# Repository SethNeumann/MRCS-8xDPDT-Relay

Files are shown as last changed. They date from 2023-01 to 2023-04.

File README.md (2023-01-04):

# REPO NAME: MRCS-8xDPDT-Relay
## License: Creative Commons Attribution-NonCommercial-ShareAlike

MRCS-8xDPDT-Relay - 8 channel DPDT Relay board with Arduino Relay compatible input

8 G5/JRC-19F/DY2 style relays, canbe powered from 5V from Arduino Relay Controller or any DC voltage coil available up to 48.
Uses ULN-2803 as buffer and for snubber diodes.
One side of each relay has cuttable traces normally set to +relayV and GND

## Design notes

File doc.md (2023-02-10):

MRCS-8xDPDT-Relay - 8 channel DPDT Relay board with Arduino Relay compatible input

8 G5V2/JRC-19F/DY2 style relays, can be powered from 5V from Arduino Relay Controller or any DC voltage coil available up to 48VDC.
Uses ULN-2803 as driver and for snubber diodes.

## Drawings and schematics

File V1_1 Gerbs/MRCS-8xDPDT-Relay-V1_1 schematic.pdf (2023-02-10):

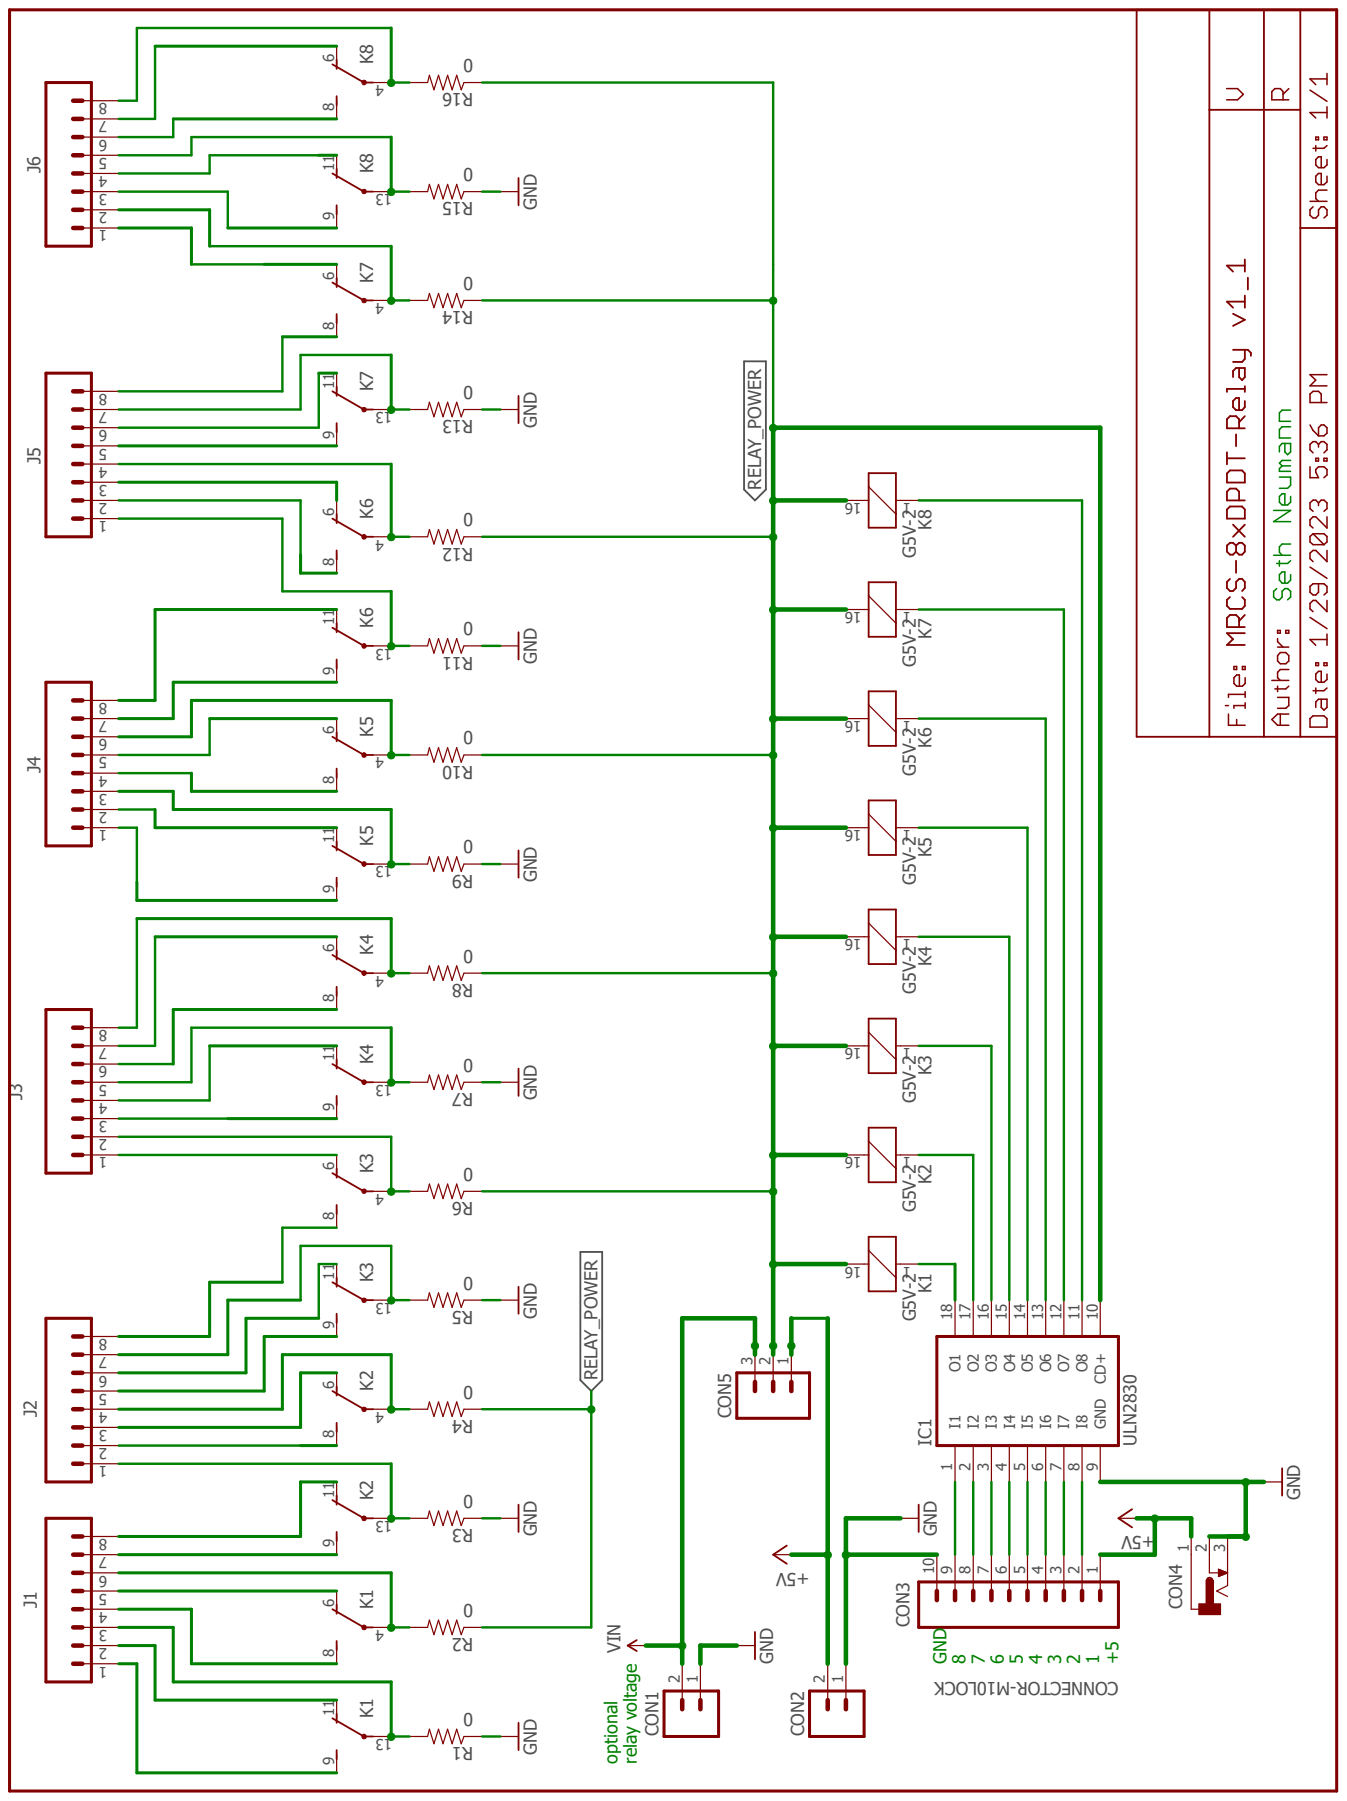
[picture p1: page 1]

+5V GND VIN G5V-2 G5V-2 G5V-2 G5V-2 G5V-2 G5V-2 G5V-2 G5V-2 0000000000000000 GND GND GND GND GND GND GND GND 10987654321 CON3 IC1I1 1 I2 2 I3 3 I4 4 I5 5 I6 6 I7 7 I8 8 O8 11 O1 18 O2 17 O3 16 O4 15 O5 14 O6 13 O7 12 CD+ 10 GND 9 12345678 J1 12345678 J2 12345678 J3 12345678 J4 12345678 J5 12345678 J6 CON4 123 CON1 21 CON2 21 321 CON5 K1

R16 RELAY_POWER RELAY_POWER GND 87654321+5 optional relay voltage

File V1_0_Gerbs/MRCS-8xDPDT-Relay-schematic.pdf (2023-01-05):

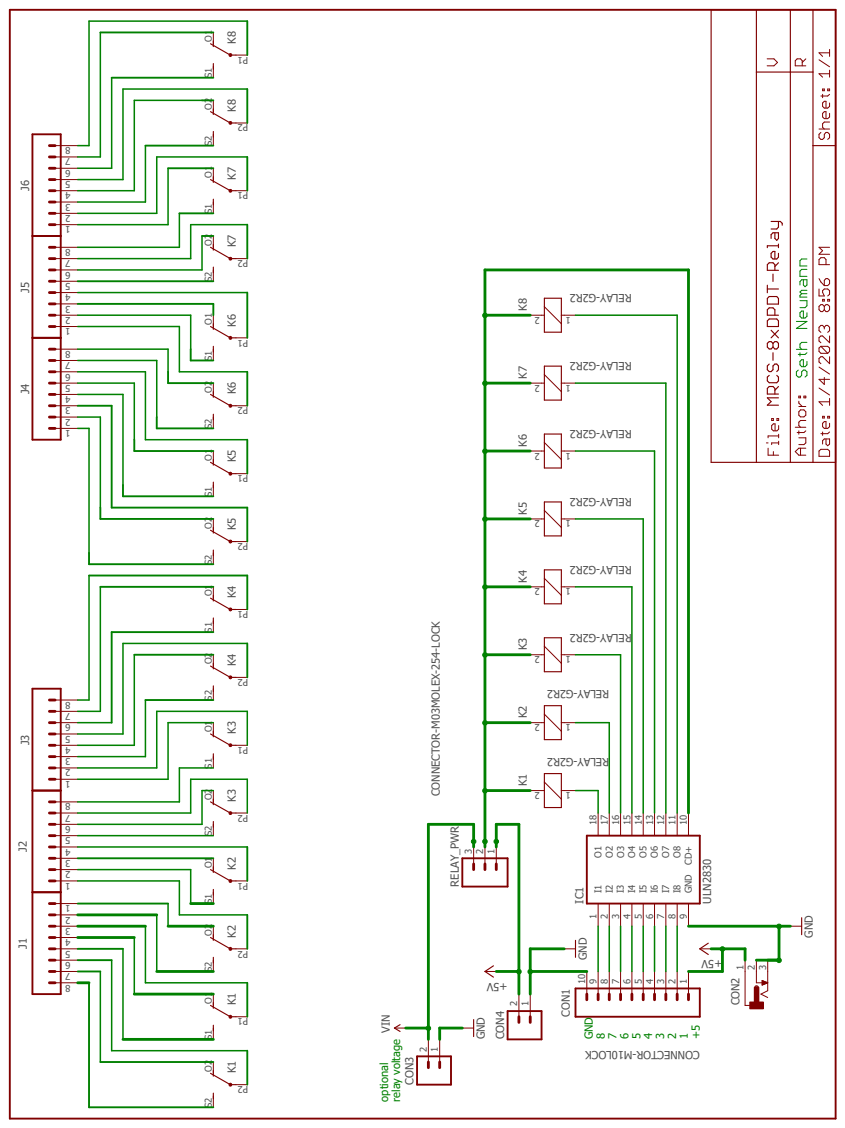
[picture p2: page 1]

P2 IC1I1 1 I2 2 I3 3 I4 4 I5 5 I6 6 I7 7 I8 8 O8 11 O1 18 O2 17 O3 16 O4 15 O5 14 O6 13 O7 12 CD+ 10 GND 9 12345678 J1 12345678 J2 12345678 J3 12345678 J4 12345678 J5 12345678 J6 CON2 123 CON3 21 CON4 21 321 RELAY_PWR GND 87654321+5 optional relay voltage

+5V GND VIN CONNECTOR-M03MOLEX-254-LOCK 10987654321 CON1 2 1 K1 O1 K1 S1 P1 O2 K1 S2

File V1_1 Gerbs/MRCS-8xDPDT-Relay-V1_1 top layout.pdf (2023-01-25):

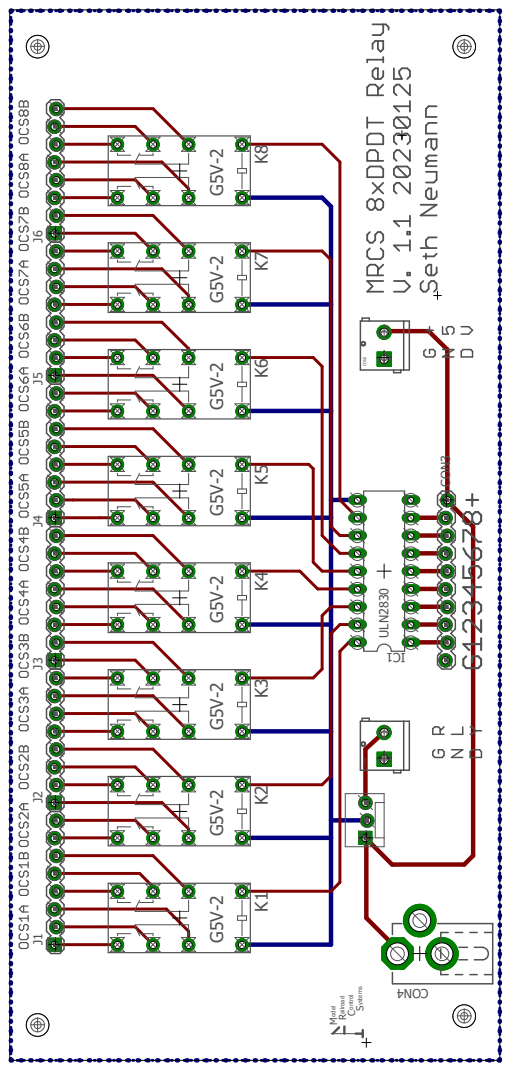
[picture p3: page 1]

MRCSystems ontrol ailroad odel CON3

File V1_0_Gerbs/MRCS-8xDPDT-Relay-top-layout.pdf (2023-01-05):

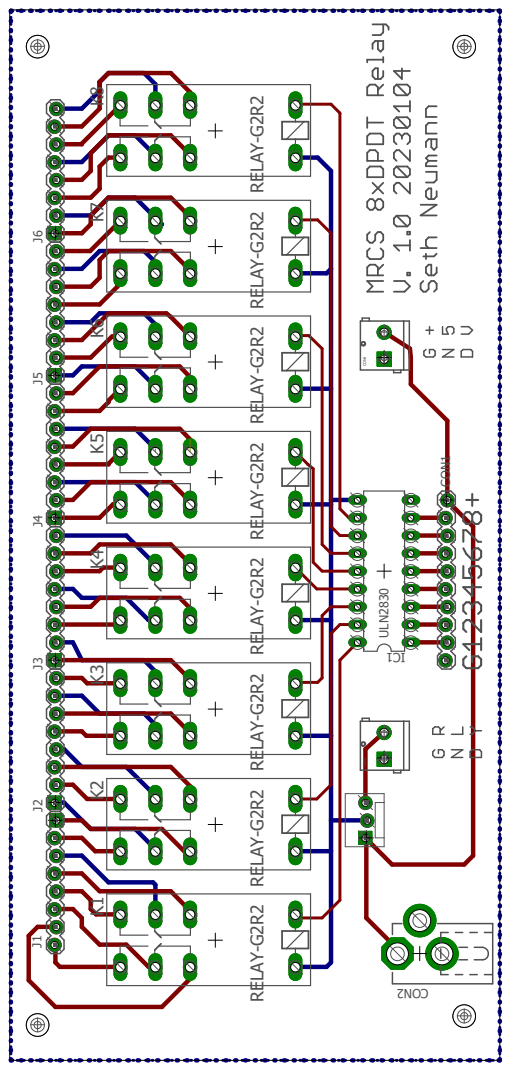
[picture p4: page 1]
CON1 K1 K2 K3 K4 K5 K6 K7 K8 IC1 J1 J2 J3 J4 J5 J6

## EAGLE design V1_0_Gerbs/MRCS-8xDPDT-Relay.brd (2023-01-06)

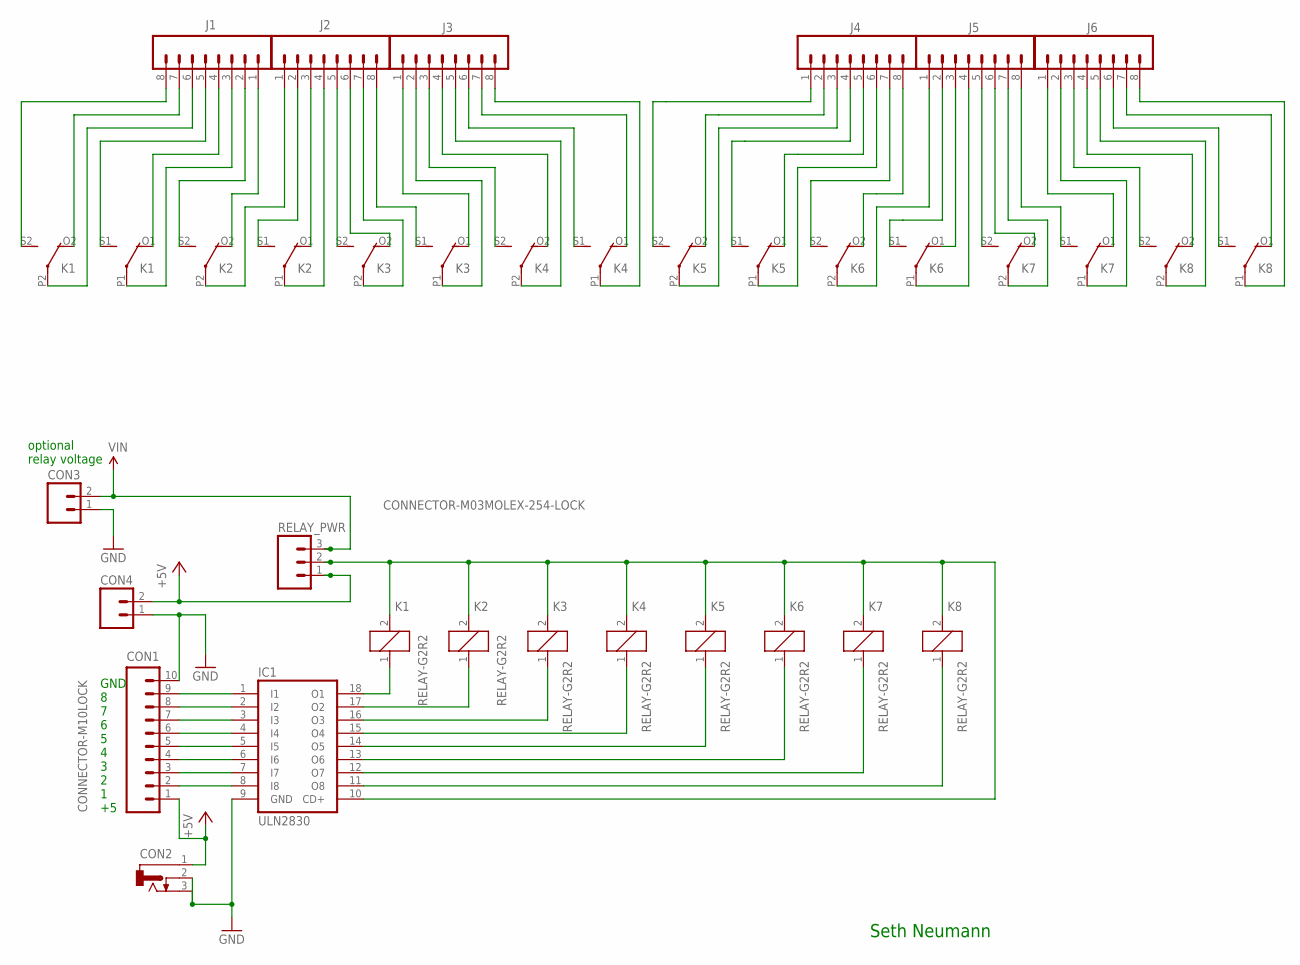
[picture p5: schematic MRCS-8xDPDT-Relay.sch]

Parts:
CON1: CONNECTOR-M10LOCK; 1X10_LOCK
CON2: CONNECTOR-DC-POWER-RA; DCJ0202
CON3, CON4: CONNECTOR-M023.5MM-LOCK; SCREWTERMINAL-3.5MM-2_LOCK
IC1: ULN2830; DIL18
J1, J2, J3, J4, J5, J6: CONNECTOR-M08LOCK; 1X08_LOCK
K1, K2, K3, K4, K5, K6, K7, K8: RELAY-G2R2; G2R2
RELAY_PWR: CONNECTOR-M03MOLEX-254-LOCK; MOLEX-1X3_LOCK

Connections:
+5V: CON1.1, CON2.1, CON4.2 (B), RELAY_PWR.1
GND: CON1.10, CON2.2, CON2.3, CON3.1 (A), CON4.1 (A), IC1.9 (GND)
unnamed: CON1.9, IC1.1 (I1)
unnamed: CON1.8, IC1.2 (I2)
unnamed: CON1.7, IC1.3 (I3)
unnamed: CON1.6, IC1.4 (I4)
unnamed: CON1.5, IC1.5 (I5)
unnamed: CON1.4, IC1.6 (I6)
unnamed: CON1.3, IC1.7 (I7)
unnamed: CON1.2, IC1.8 (I8)
unnamed: IC1.17 (O2), K2.1
unnamed: IC1.16 (O3), K3.1
unnamed: IC1.15 (O4), K4.1
unnamed: IC1.14 (O5), K5.1
unnamed: IC1.18 (O1), K1.1
unnamed: IC1.13 (O6), K6.1
unnamed: IC1.12 (O7), K7.1
unnamed: IC1.11 (O8), K8.1
unnamed: IC1.10 (CD+), K1.2, K2.2, K3.2, K4.2, K5.2, K6.2, K7.2, K8.2, RELAY_PWR.2
unnamed: J1.8, K1.S2 (S)
unnamed: J1.7, K1.O2 (O)
unnamed: J1.6, K1.P2
unnamed: J1.5, K1.S1 (S)
unnamed: J2.3, K2.O1 (O)
unnamed: J1.3, K1.P1
unnamed: J1.2, K2.S2 (S)
unnamed: J1.1, K2.O2 (O)
unnamed: J2.1, K2.P2
unnamed: J2.2, K2.S1 (S)
unnamed: J4.3, K5.P2
unnamed: J2.4, K2.P1
unnamed: J2.7, K3.P2
unnamed: J2.6, K3.O2 (O)
unnamed: J2.8, K3.S1 (S)
unnamed: J2.5, K3.S2 (S)
unnamed: J3.1, K3.O1 (O)
unnamed: J3.2, K3.P1
unnamed: J3.3, K4.S2 (S)
unnamed: J3.4, K4.O2 (O)
unnamed: J3.5, K4.P2
unnamed: J3.6, K4.S1 (S)
unnamed: J3.7, K4.O1 (O)
unnamed: J3.8, K4.P1
unnamed: J5.4, K6.P1
unnamed: J5.5, K7.S2 (S)
unnamed: J5.6, K7.O2 (O)
unnamed: J5.7, K7.P2
unnamed: J5.8, K7.S1 (S)
unnamed: J6.1, K7.O1 (O)
unnamed: J6.2, K7.P1
unnamed: J6.3, K8.S2 (S)
unnamed: J6.4, K8.O2 (O)
unnamed: J6.5, K8.P2
unnamed: J6.6, K8.S1 (S)
unnamed: J6.7, K8.O1 (O)
unnamed: J6.8, K8.P1
unnamed: J5.3, K6.O1 (O)
unnamed: J5.2, K6.S1 (S)
unnamed: J5.1, K6.P2
unnamed: J4.8, K6.O2 (O)
unnamed: J4.7, K6.S2 (S)
unnamed: J4.6, K5.P1
unnamed: J4.5, K5.O1 (O)
unnamed: J4.4, K5.S1 (S)
unnamed: J4.2, K5.O2 (O)
unnamed: J4.1, K5.S2 (S)
unnamed: J1.4, K1.O1 (O)
VIN: CON3.2 (B), RELAY_PWR.3

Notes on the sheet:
Seth Neumann
GND 8 7 6 5 4 3 2 1 +5
optional relay voltage

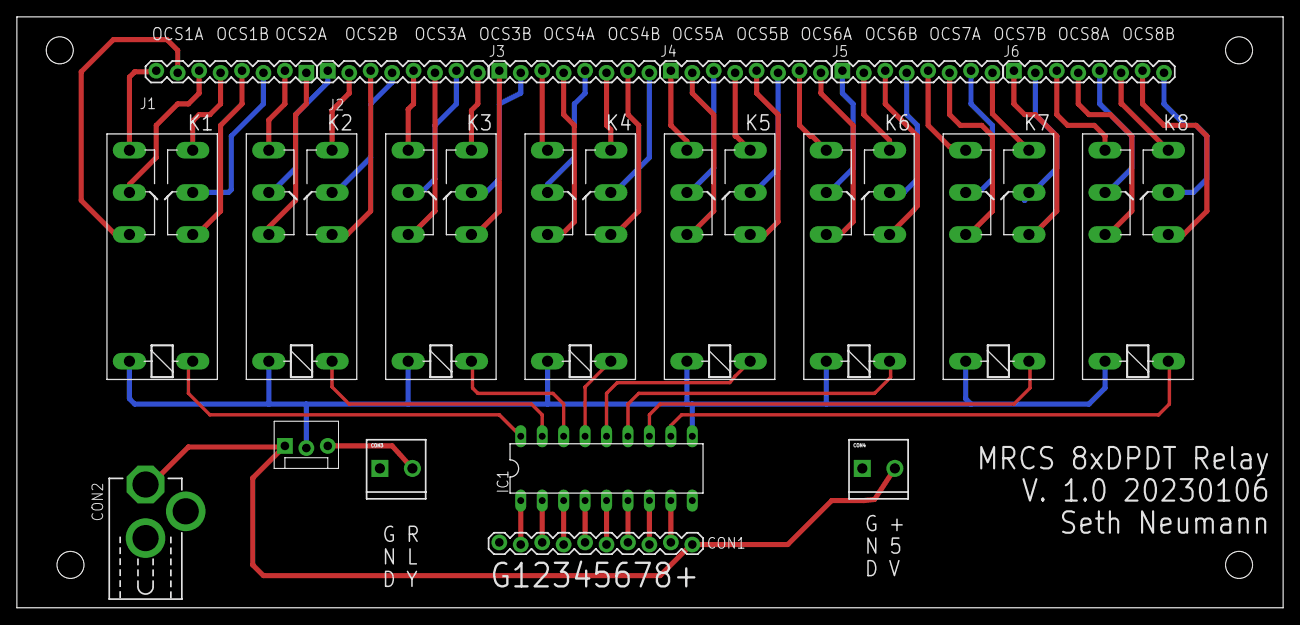
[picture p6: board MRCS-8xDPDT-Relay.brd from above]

Board: 2 copper layers, 150.0 x 70.0 mm, 23 parts (0 on the bottom side), 68 nets.

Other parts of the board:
U$1: CA-PROP65WARNING
U$2: MRCSLOGOBTM
U$3: MRCSLOGOTOP

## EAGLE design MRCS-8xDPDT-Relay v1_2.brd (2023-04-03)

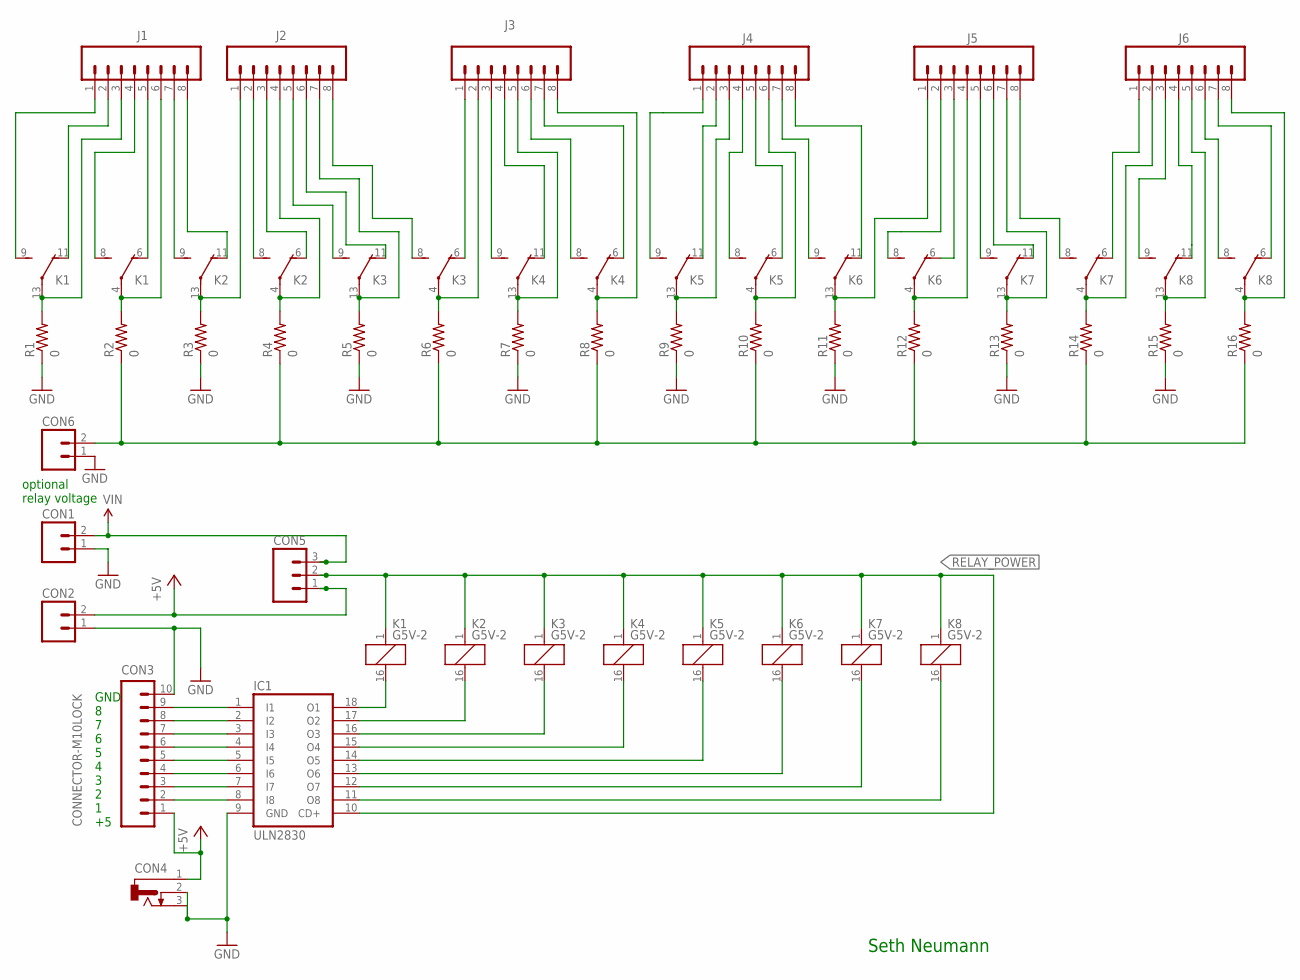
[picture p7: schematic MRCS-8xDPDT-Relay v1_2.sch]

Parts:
CON1, CON2, CON6: CONNECTOR-M023.5MM-LOCK; SCREWTERMINAL-3.5MM-2_LOCK
CON3: CONNECTOR-M10LOCK; 1X10_LOCK
CON4: CONNECTOR-DC-POWER-RA; DCJ0202
CON5: CONNECTOR-M03MOLEX-254-LOCK; MOLEX-1X3_LOCK
IC1: ULN2830; DIL18
J1, J2, J3, J4, J5, J6: CONNECTOR-M08LOCK; 1X08_LOCK
K1, K2, K3, K4, K5, K6, K7, K8: G5V-2
R1, R2, R3, R4, R5, R6, R7, R8, R9, R10, R11, R12, R13, R14, R15, R16: 0; CUT-R

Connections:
+5V: CON2.2 (B), CON3.1, CON4.1, CON5.1
AUX_COMMON: CON6.2 (B), R2.P2 (1), R4.P2 (1), R6.P2 (1), R8.P2 (1), R10.P2 (1), R12.P2 (1), R14.P2 (1), R16.P2 (1)
GND: CON1.1 (A), CON2.1 (A), CON3.10, CON4.2, CON4.3, CON6.1 (A), IC1.9 (GND), R1.P2 (1), R3.P2 (1), R5.P2 (1), R7.P2 (1), R9.P2 (1), R11.P2 (1), R13.P2 (1), R15.P2 (1)
unnamed: CON3.9, IC1.1 (I1)
unnamed: CON3.8, IC1.2 (I2)
unnamed: CON3.7, IC1.3 (I3)
unnamed: CON3.6, IC1.4 (I4)
unnamed: CON3.5, IC1.5 (I5)
unnamed: CON3.4, IC1.6 (I6)
unnamed: CON3.3, IC1.7 (I7)
unnamed: CON3.2, IC1.8 (I8)
unnamed: IC1.17 (O2), K2.16 (2)
unnamed: IC1.16 (O3), K3.16 (2)
unnamed: IC1.15 (O4), K4.16 (2)
unnamed: IC1.14 (O5), K5.16 (2)
unnamed: J1.7, K2.9 (S)
unnamed: IC1.13 (O6), K6.16 (2)
unnamed: IC1.12 (O7), K7.16 (2)
unnamed: IC1.11 (O8), K8.16 (2)
unnamed: J1.1, K1.9 (S)
unnamed: J1.2, K1.11 (O)
unnamed: J1.3, K1.13, R1.P1 (2)
unnamed: J1.4, K1.8 (S)
unnamed: IC1.18 (O1), K1.16 (2)
unnamed: J1.5, K1.6 (O)
unnamed: J1.6, K1.4, R2.P1 (2)
unnamed: J1.8, K2.11 (O)
unnamed: J2.1, K2.13, R3.P1 (2)
unnamed: J2.2, K2.8 (S)
unnamed: J4.3, K5.13, R9.P1 (2)
unnamed: J2.4, K2.4, R4.P1 (2)
unnamed: J2.7, K3.13, R5.P1 (2)
unnamed: J2.6, K3.11 (O)
unnamed: J2.8, K3.8 (S)
unnamed: J2.5, K3.9 (S)
unnamed: J3.1, K3.6 (O)
unnamed: J3.2, K3.4, R6.P1 (2)
unnamed: J3.3, K4.9 (S)
unnamed: J3.4, K4.11 (O)
unnamed: J3.5, K4.13, R7.P1 (2)
unnamed: J3.6, K4.8 (S)
unnamed: J3.7, K4.6 (O)
unnamed: J3.8, K4.4, R8.P1 (2)
unnamed: J5.4, K6.4, R12.P1 (2)
unnamed: J5.5, K7.9 (S)
unnamed: J5.6, K7.11 (O)
unnamed: J5.7, K7.13, R13.P1 (2)
unnamed: J5.8, K7.8 (S)
unnamed: J6.1, K7.6 (O)
unnamed: J6.2, K7.4, R14.P1 (2)
unnamed: J6.3, K8.9 (S)
unnamed: J6.4, K8.11 (O)
unnamed: J6.5, K8.13, R15.P1 (2)
unnamed: J6.6, K8.8 (S)
unnamed: J6.7, K8.6 (O)
unnamed: J6.8, K8.4, R16.P1 (2)
unnamed: J5.3, K6.6 (O)
unnamed: J5.2, K6.8 (S)
unnamed: J5.1, K6.13, R11.P1 (2)
unnamed: J4.7, K6.9 (S)
unnamed: J4.6, K5.4, R10.P1 (2)
unnamed: J4.5, K5.6 (O)
unnamed: J4.4, K5.8 (S)
unnamed: J2.3, K2.6 (O)
unnamed: J4.2, K5.11 (O)
unnamed: J4.1, K5.9 (S)
unnamed: J4.8, K6.11 (O)
RELAY_POWER: CON5.2, IC1.10 (CD+), K1.1, K2.1, K3.1, K4.1, K5.1, K6.1, K7.1, K8.1
VIN: CON1.2 (B), CON5.3

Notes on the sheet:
Seth Neumann
GND 8 7 6 5 4 3 2 1 +5
optional relay voltage

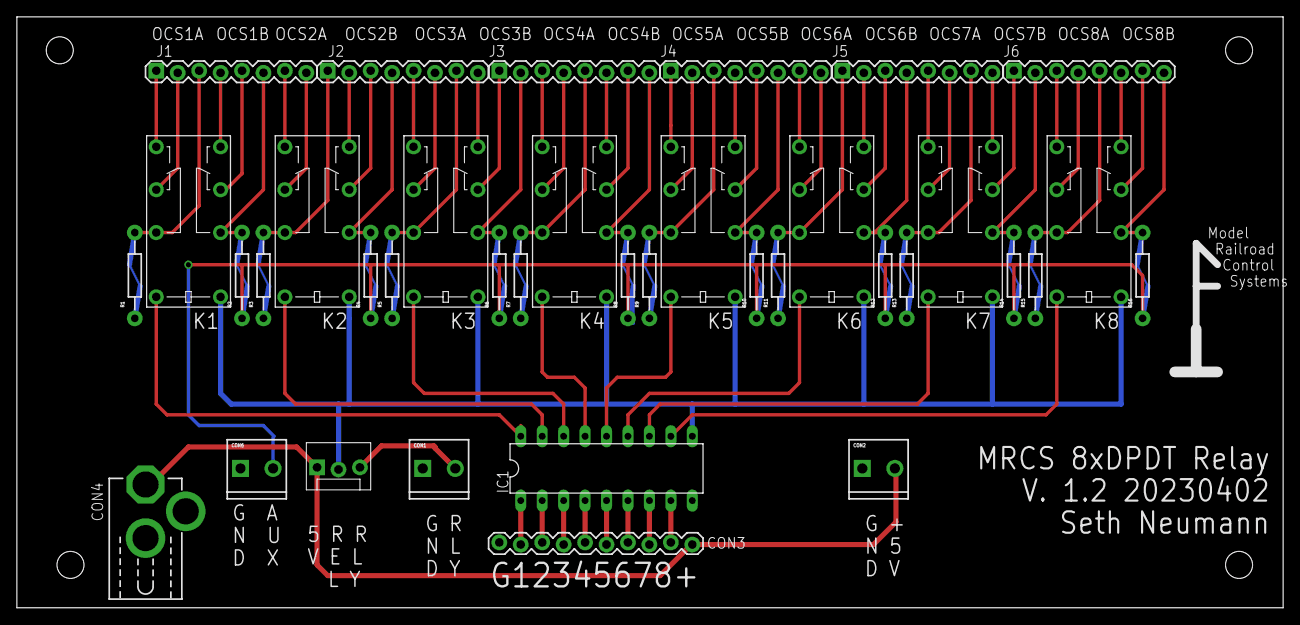
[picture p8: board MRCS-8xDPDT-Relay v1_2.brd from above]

Board: 2 copper layers, 150.0 x 70.0 mm, 40 parts (0 on the bottom side), 69 nets.

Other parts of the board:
U$1: CA-PROP65WARNING
U$2: MRCSLOGOBTM
U$4: MRCS-LOGO-LARGE

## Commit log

2023-01-04 early draft of board for Jon
    [MRCS-8xDPDT-Relay.brd, MRCS-8xDPDT-Relay.sch]
2023-01-04 early doodling
    [MRCS-8xDPDT-Relay.brd, MRCS-8xDPDT-Relay.sch]
2023-01-05 keeping Jon up to date
    adding contacts
    [MRCS-8xDPDT-Relay.brd, MRCS-8xDPDT-Relay.sch]
2023-01-05 1st pass complete
    first pass. no ground or power jumpers.
    [MRCS-8xDPDT-Relay.brd, MRCS-8xDPDT-Relay.sch]
2023-01-05 added pdfs of schematic and top layout
    for easier review
2023-01-05 corrected relay description
2023-01-06 first release send out for fab
    this was sent out for fab. First release is for test.
    [MRCS-8xDPDT-Relay.brd]
2023-01-13 correct relay types, remove optional pads
2023-01-25 Version 1.1 commit
    Changed to the proper relay (G5V2 and clones). Cleaned up a lot of messy traces.
    [MRCS-8xDPDT-Relay v1_1.brd, MRCS-8xDPDT-Relay v1_1.sch, MRCS-8xDPDT-Relay.brd]
2023-01-25 cleaned up description and corrected relay spec
2023-02-10 Release 1.1 - updated to show resistors
    this version works with the smaller relays and has cuttable traces for ground on the COM of 1 contact Relay Power on the contact of the other
2023-04-03 changes for V1.2
    1 - changed polarity of relay so polarized relays will work
    2 - Moved the second contact to a separate bus, so you can put any signal you want in by leaving the resistor uncut or cut it and use the contact independently
    3 - added connector for bus above, cleaned up labels
    [MRCS-8xDPDT-Relay v1_2.brd, MRCS-8xDPDT-Relay v1_2.sch, MRCS-8xDPDT-Relay.brd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]

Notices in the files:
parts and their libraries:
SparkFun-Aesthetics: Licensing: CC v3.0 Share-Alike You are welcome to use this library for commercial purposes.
